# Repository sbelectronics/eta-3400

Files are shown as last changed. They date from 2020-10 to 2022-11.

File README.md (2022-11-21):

# Scott's ETA-3400 Memory/IO Accessory Remake
(c) Scott Baker, http://www.smbaker.com/

youtube video: https://www.youtube.com/watch?v=gP17z7haC4o&ab_channel=smbakeryt

## Purpose

The ETA-3400 was a memory/IO accessory for Heathkit's ET-3400 and ET-3400-A trainers. It added a serial port, a cassette port, up to 4K of RAM, and 4K of ROM. The ROM included a terminal monitor that you could use to operate the trainer over serial, as well as a "Tiny Basic" ROM that allowed you to program the trainer in the BASIC programming language.

This project is a remake of that board, using slightly more modern components, but still in the vintage theme of the original.

## Recompiling the ATF16V8

The ATF16V8 is a programmable logic device that implements the IO addressing and some control line manipulation. It's programmed in a languaged called CUPL. You'll need the [WinCUPL tool](https://www.microchip.com/design-centers/fpgas-and-plds/splds-cplds/pld-design-resources) from Microchip in order to recompile the PLD. The desired output is the JED file, which you can program using a programmer such as TL866 with minipro software.

## Burning the ROM

I wrote a small python tool, makerom.py, that loaded the original heathkit ROMs into a 4K rom image (the way they're addressed is a little bit weird, the trainer puts them at 0x1400 to 0x23FF). I used a TL866 with minipro to burn it to a 28C64 EEPROM chip.

You might notice that roms/combined.bin is 5K instead of 4K. That's a mistake (the last 1K is all zeros), but that's also the way it was when I burned my ROM and made my video, so I left it as-is. In the future, I may look into finding a way to load more programs into the remainder of the ROM and make it addressable.

## Setting up the raspberry pi zero

The raspberry pi zero is entirely optional (the board features a RS232 port that can be used with an external terminal), but offers the ability to build a terminal directly into your ETA-3400. Some instructions on setting up the Pi Zero W

```bash
# disable serial console
sudo raspi-config
  5 - interfacing options
    P6 - serial
        No login shell
        Yes serial interface enabled

# install minicom
sudo apt-get -y install minicom
sudo minicom -s
  Port - /dev/serial0
  Baud - 2400
  Bits - 7,E,1
  Flow Control - off

# as an alternative to minicom, picocom can be used
sudo apt-get -y install picocom
picocom /dev/ttyS0 --baud 2400 -p 1 -d 7 -y e

Note: You'll want to set an end-of-line delay in minicom or picocom if you want to be able to do text uploads to basic. I recommend 325 milliseconds. Otherwise, your terminal
might send the next character while basic is saving the freshly-entered line, and the first character of the next line will be lost.
```

## Static RAM Notes

My tests of several 62256 RAM variants that I obtained. Note that I have only performed a short test on each one to verify whether
BASIC loaded properly and was able to run a short program. Your mileage may vary.

* AS6C62256-55PCN (Mouser) 55ns part DOES NOT WORK correctly. 70ns part (-70PCN) is fine but hard to find.
* HM62256LP-12 (Jameco 42850). According to catalog is a 150ns part, but as received with -12 number is probably 120ns. Tested and works.
* KM62256BLP-10 (Jameco 42833). 100ns. Tested and works.
* HM62256BLP-7 (Jameco 82472). 70ns low power. DOES NOT WORK.
* MS62256L-70PC (ebay). 70ns. Tested and works.
* CY62256NLL-70PXC. 70ns. Tested and works.

## Gerbers

The gerbers are present in the gerbers directory.

* gerbers/v-0.2-initial .. This was my initial order, sent to jlcpcb, to make the boards used in the video.

## Resources and Acknowlegements

* The [ET-3400 group](https://groups.io/g/ET-3400) is a great resource, and several people there were helpful and supportive of this project.

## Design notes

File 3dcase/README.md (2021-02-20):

# 3D Printed Case

Makes extensive use of heat-set threadserts to connect the pieces together. Double-faced tape is used to stick
some mounts onto the bottom of the trainer, and then magnets are used to attach the case to the mounts. This
makes the case easily removable (my youtube video ought to give a reasonable idea on how the case snaps on
and off).

Here is a list of hardware necessary to complete the case:

* Magnets - use 10mm x 3mm, commonly available on Amazon
* M2.5 machine screws - Usually a small assortment from Amazon will yield a variety of acceptable sizes
* 2.5mm heat-set thread inserts - I usually get these on eBay under the auction description "Qty 100 M2.5 2.5mm M2.5-0.45 Brass Threaded Heat Set Screw Inserts - 3D Printing"

Print the following:

* (1) eta-3400-front.stl - front panel
* (2) eta-3400-side.stl - sides
* (1) eta-3400-back.stl - back panel
* (1) eta-3400-tray.stl - attaches to the back panel and holds the PCB
* (1) eta-3400-base.stl - attachs between the tray and the front panel, providing additional rigidity
* (2) eta-3400-mount.stl - sticks to the trainer with double-faced tape

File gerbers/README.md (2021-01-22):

This directory holds gerbers that can be used to fabricate the pcboards.

A few different ET-3400 related projects are in here

v0.10 and v0.9 hold the gerbers for the ETA-3400 memory/io board. v0.10 is the latest.

et-3400-6809-v0.2 holds gerbers for my clone for the 6809 adapter. This adapter is a separate project
and is not needed to build the memory/io accessory.

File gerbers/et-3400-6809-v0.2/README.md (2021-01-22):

This directory holds my clone of the ET-3404 6089 adapter.

More about it at https://www.smbaker.com/cloning-the-et-3404-6809-adapter-for-the-heathkit-et-3400

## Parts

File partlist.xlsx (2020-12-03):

Part | Value | Quantity | Description | Source
C1 | 0.0047uF | 1 |  | digikey BC2683CT-ND
C2 | 2.2uF | 1 |  | digikey 445-173575-1-ND
C3 | 0.047uF | 1 |  | digikey BC2686CT-ND
C4-C14 | 0.1uF | 11 | bypass capacitor | digikey 399-4264-ND
 | 470uf/16V | 1 | additional stability when using pi; place across the 5V and GND pins of SV1
D1, D2 | 1N4148 | 2 |  | digikey 1N4148FS-ND
IC1 | 28C64 | 1 | EEPROM | digikey AT28C64B-15PU-ND
IC2 | AS6C62256 | 1 | RAM | digikey 1450-1182-5-ND (use the 70ns version, not the 55ns)
IC3 | 6821 PIA | 1 | PIA | ebay
IC4 | ATF16V8BP3 | 1 | PLD address decode | digikey ATF16V8B-15PU-ND
IC5 | MAX202 | 1 | serial driver | digikey MAX202ECPE+-ND
IC6 | MC3302P | 1 | comparator | digikey 296-17223-5-ND
J1 | DCJACK 5.5x2.1 | 1 | [Optional] external power | digikey CP-002A-ND (not verified, looks right)
JP1 | 1x3 header |  | [Optional] spare input to PLD | digikey, S1012EC-40-ND (cut to size)
JP2 | 2x6 header |  | Baud select jumper
JP3 | 1x2 header |  | Jumper, enables power from ET3400
JP4 | 1x2 header |  | Jumper, enables power to pi socket
JP5 | 1x3 header |  | Jumper, cassette output gain
JP6 | 2x2 header |  | Jumpers, ser output | digikey, S2012EC-20-ND (cut to size)
JP7 | 2x2 header |  | Jumpers, max202
R1, R5, R8 | 100K | 3 |  | digikey S100KCACT-ND
R2, R4, R9, R10 | 1K | 4 |  | digikey S1KCACT-ND
R3, R7, R11, R20 | 10K | 4 |  | digikey S10KCACT-ND
R6 | 3.3K | 1 |  | digikey S3.3KCACT-ND
R12 | 100 ohm | 1 |  | digikey S130CACT-ND
R13-R19 | 150 ohm | 7 | RasPi protection resistors | digikey S150CACT-ND
R21 | 0 (jumper) | 1 | a chunk of wire will do
RN1 | 2.2K x 6 SIP | 1 | 2.2Kx6 bussed sip resistor | digikey 4607X-101-222LF-ND
SV1 | 1x5 RA header | 1 | [Optional] I2C header from pi | digikey S1111EC-40-ND (cut to size)
SV2 or SV3 | 1x4 RA header | 1 |  | digikey S1132EC-40-ND (cut to size, tall)
U$2 | 2x40 header | 1 |  | digikey, S2012EC-20-ND (cut to size)
X1 | RASPI_BOAR |  | [Optional] Header for Pi Zero W
X2 | DB25 | 1 | DB25 connector | Digikey, AE10935-ND
 | shunt jumpers |  |  | Digikey, S9337-ND
CAB1 | 40-ribbon |  | 40 pin ribbon cable |  | ETA-3400 to ET-3400 cable
IDC1, IDC2 | 2x20 IDC conn |  | 2x20 IDC ribbon cable connector |  | ETA-3400 to ET-3400 connectors

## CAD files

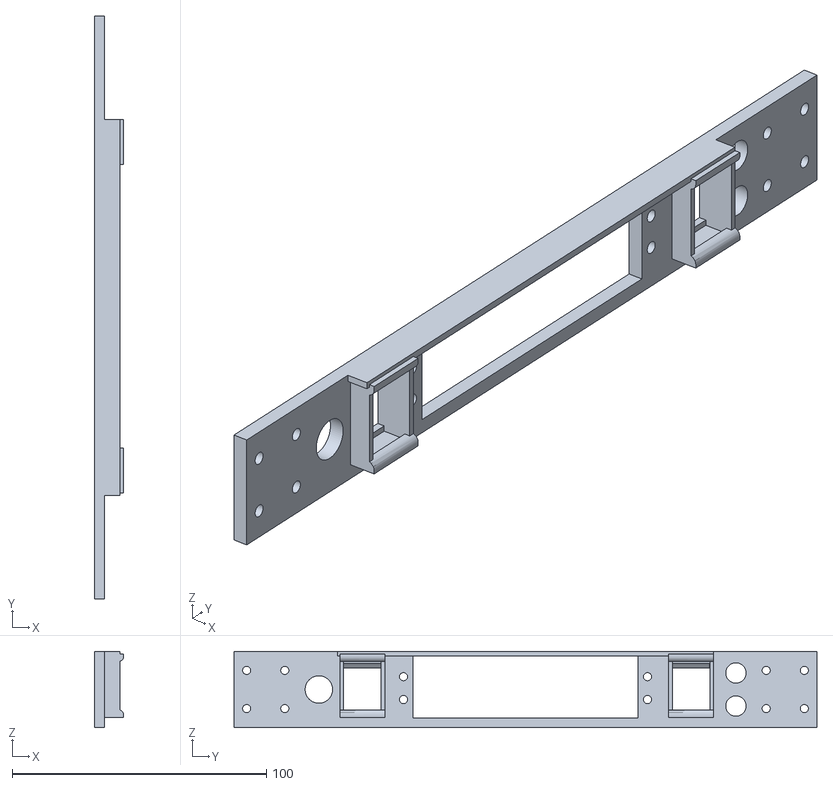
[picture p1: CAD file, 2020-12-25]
3dcase/eta-3400-back.stl
11.5 x 229.4 x 30.0

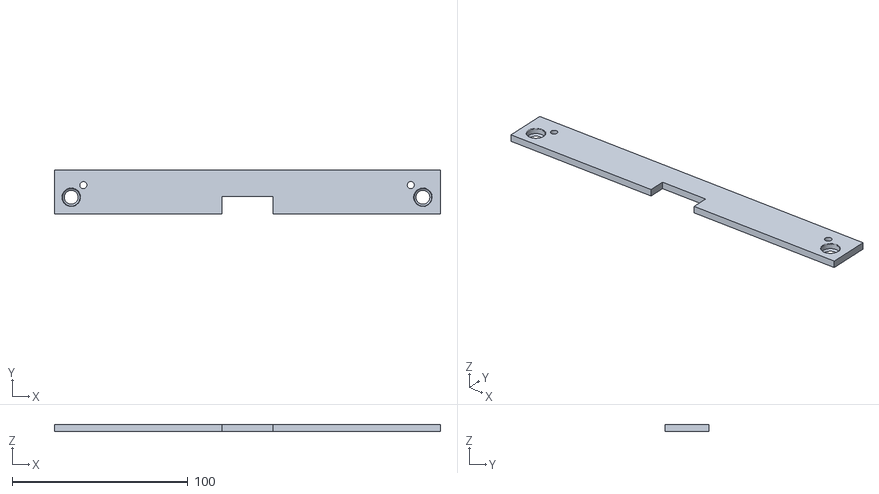
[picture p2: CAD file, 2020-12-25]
3dcase/eta-3400-mount.stl
219.5 x 25.0 x 4.00

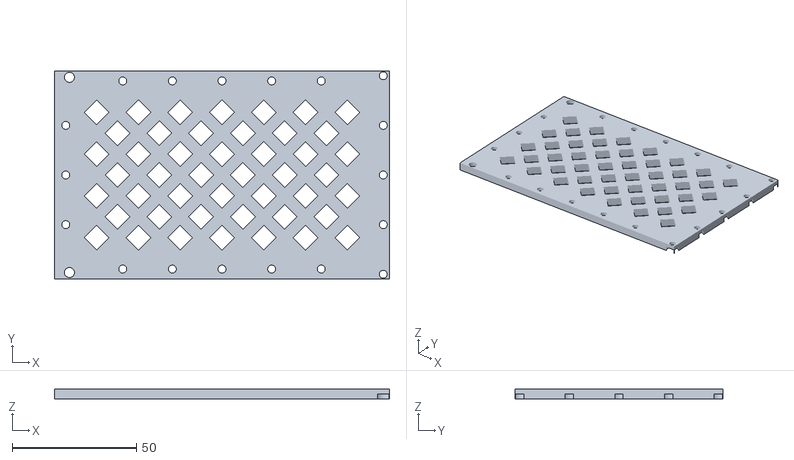
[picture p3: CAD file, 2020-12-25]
3dcase/eta-3400-base-perforated.stl
135.0 x 83.8 x 4.00

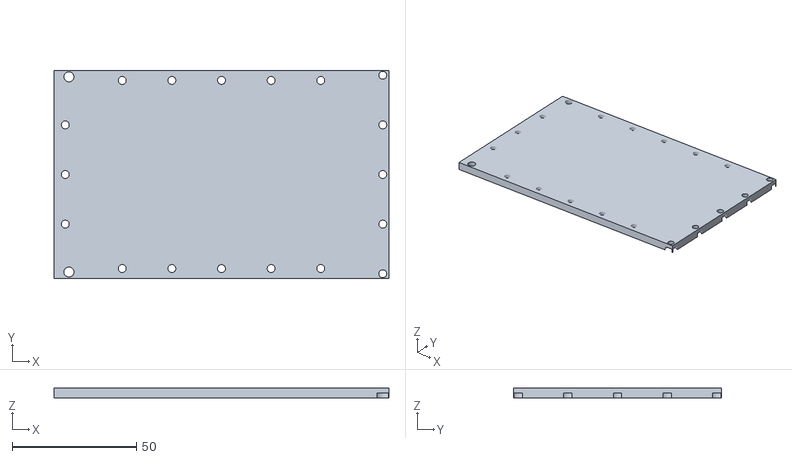
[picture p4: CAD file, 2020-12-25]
3dcase/eta-3400-base.stl
135.0 x 83.8 x 4.00

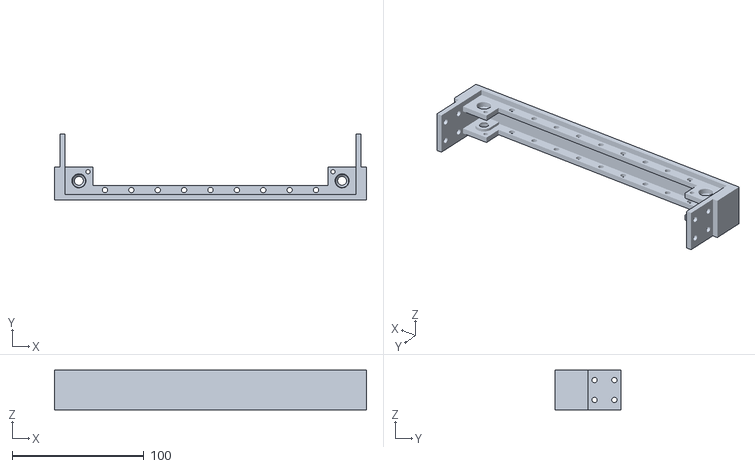
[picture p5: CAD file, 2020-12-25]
3dcase/eta-3400-side.stl
236.5 x 50.0 x 30.0

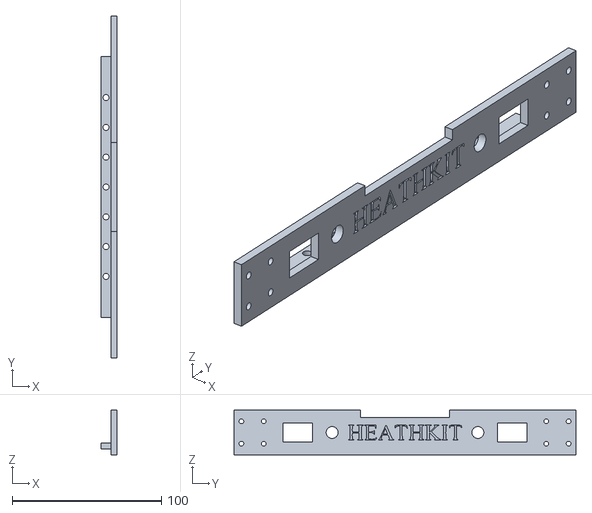
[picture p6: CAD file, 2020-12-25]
3dcase/eta-3400-front.stl
11.0 x 229.4 x 30.0

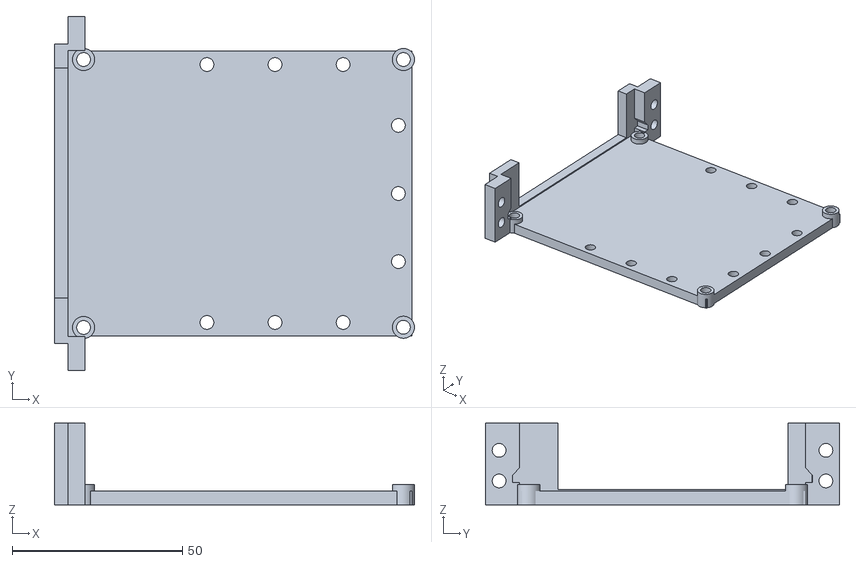
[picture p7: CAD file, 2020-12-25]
3dcase/eta-3400-tray.stl
105.8 x 104.0 x 24.0

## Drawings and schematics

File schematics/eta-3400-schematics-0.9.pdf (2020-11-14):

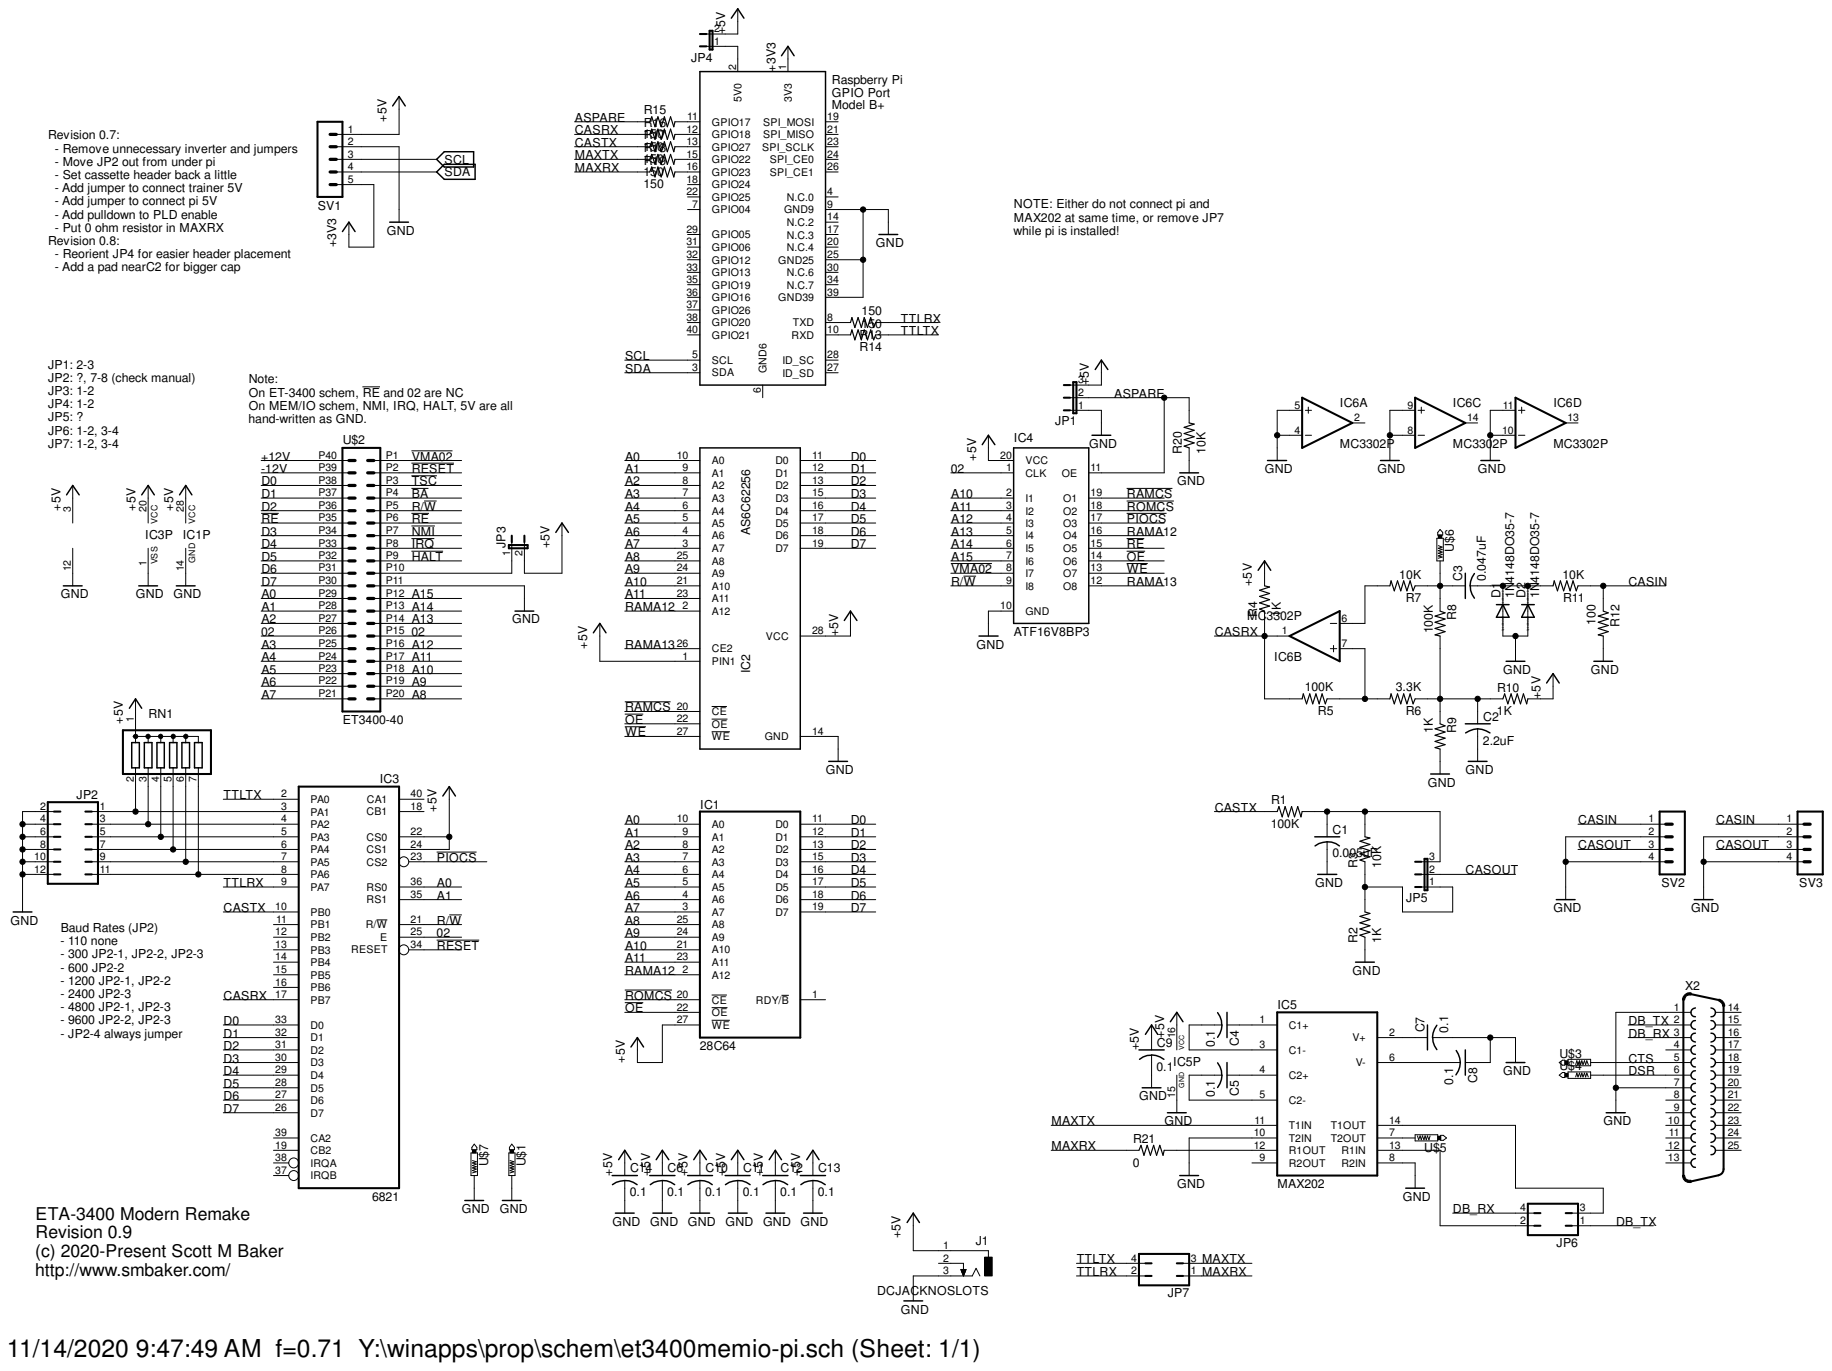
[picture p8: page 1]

Revision 0.7:
- Remove unnecessary inverter and jumpers
- Move JP2 out from under pi
- Set cassette header back a little
- Add jumper to connect trainer 5V
- Add jumper to connect pi 5V
- Add pulldown to PLD enable
- Put 0 ohm resistor in MAXRX
Revision 0.8:
- Reorient JP4 for easier header placement
- Add a pad nearC2 for bigger cap

NOTE: Either do not connect pi and
MAX202 at same time, or remove JP7
while pi is installed!

Note:
On ET-3400 schem, RE and 02 are NC
On MEM/IO schem, NMI, IRQ, HALT, 5V are all
hand-written as GND.

ETA-3400 Modern Remake
Revision 0.9
(c) 2020-Present Scott M Baker
http://www.smbaker.com/

GND GND GND GND GND

11/14/2020 9:47:49 AM f=0.71 Y:\winapps\prop\schem\et3400memio-pi.sch (Sheet: 1/1)

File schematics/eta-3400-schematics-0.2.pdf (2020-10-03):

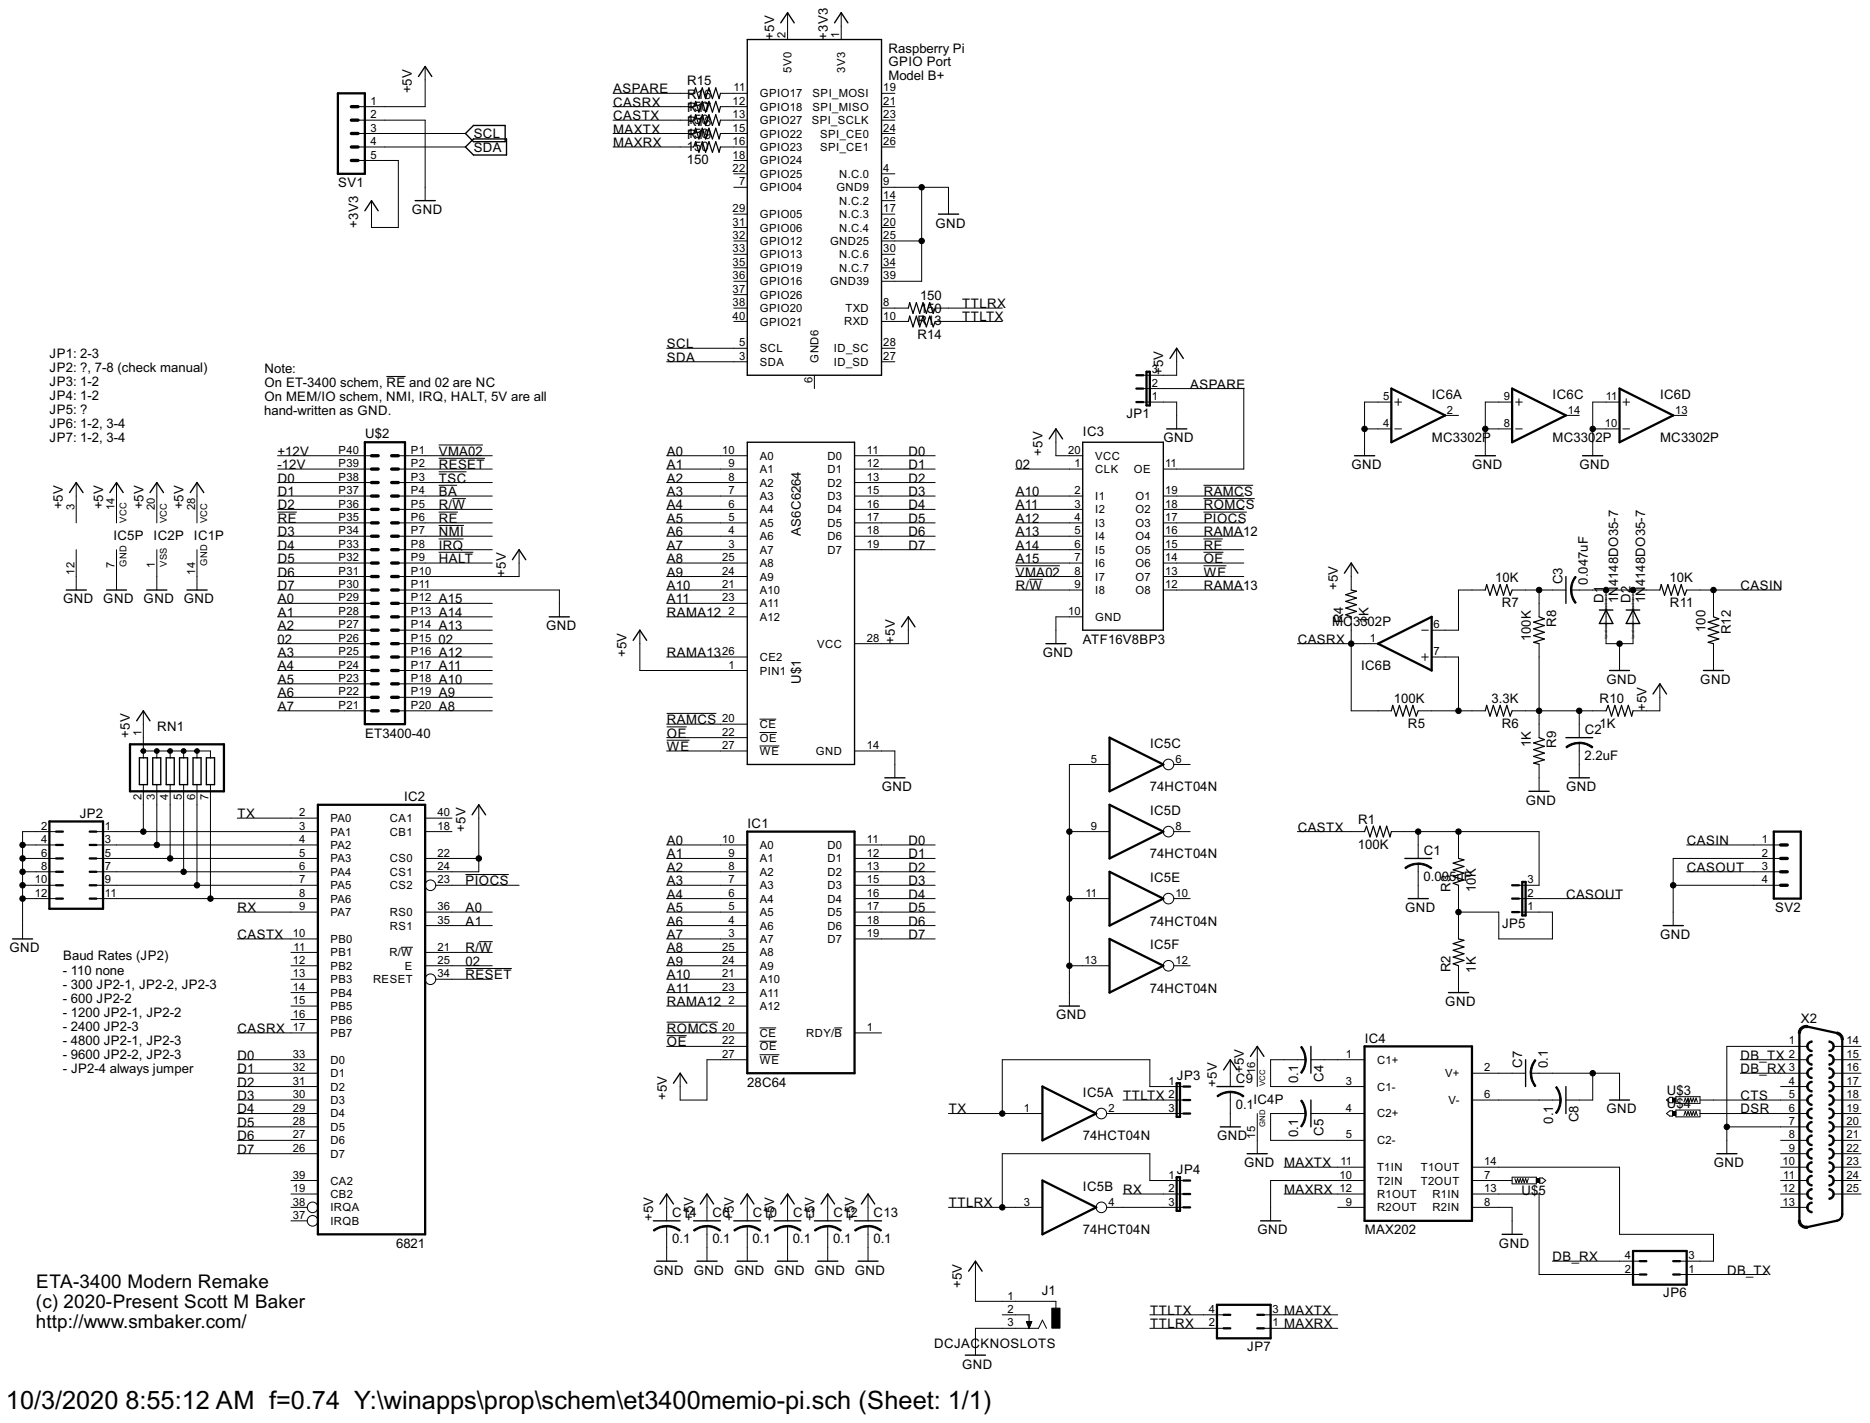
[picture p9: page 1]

Raspberry Pi GPIO Port Model B+

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

ETA-3400 Modern Remake
(c) 2020-Present Scott M Baker http://www.smbaker.com/

GND GND GND GND GND

10/3/2020 8:55:12 AM f=0.74 Y:\winapps\prop\schem\et3400memio-pi.sch (Sheet: 1/1)

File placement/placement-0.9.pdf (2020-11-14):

# (pi upside-down)

3 | 2 | 1

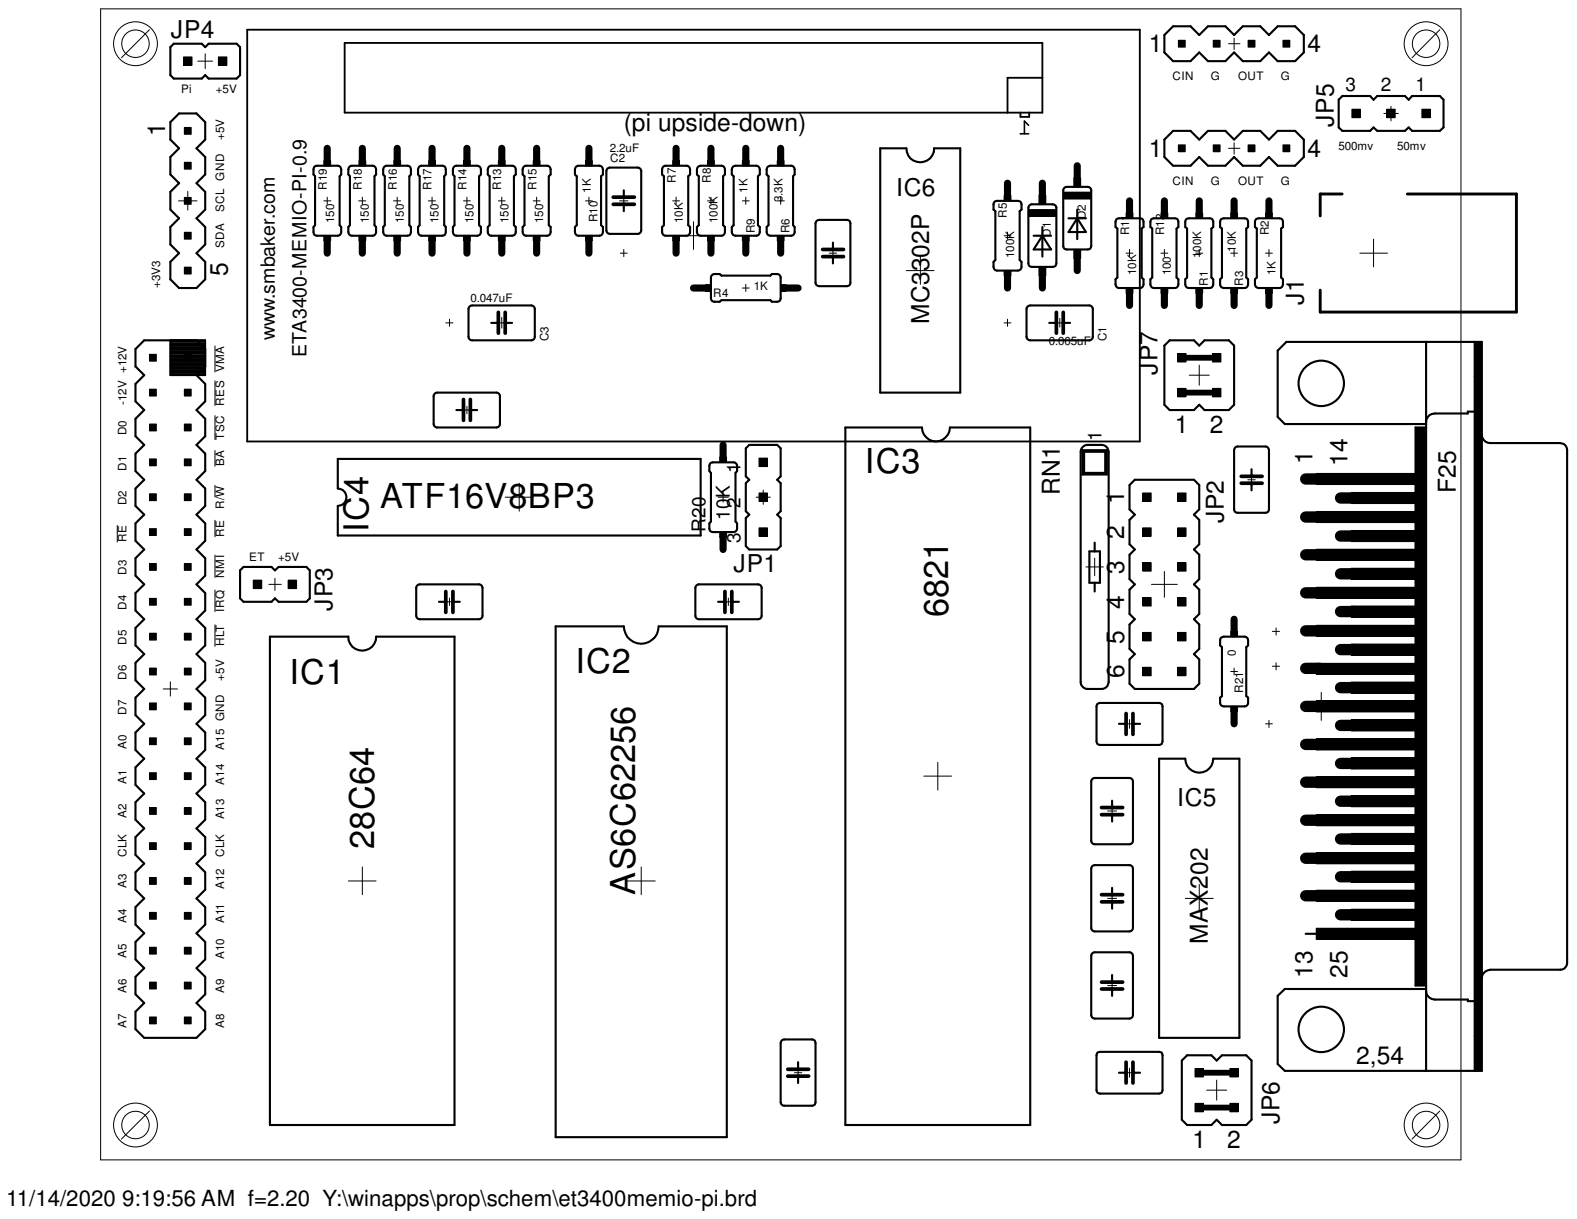
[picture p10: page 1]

VMA RES TSC BA R/W RE NMI IRQ HLT +5V GND A15 A14 A13 A12 A11 A10 CLK A9

11/14/2020 9:19:56 AM f=2.20 Y:\winapps\prop\schem\et3400memio-pi.brd

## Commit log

2020-10-03 check in gerbers
    [et3400memio-pi.GBL, et3400memio-pi.GBO, et3400memio-pi.GBS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]
2020-10-03 check in schematic
2020-10-05 working on LOD sample game
2020-11-14 check in 0.9 schematic and placement
    [partlist.xlsx]
2020-11-15 check in part list update
    [partlist.xlsx]
2020-12-03 check in v0.9 and v0.10 gerbers
    [et3400memio-pi.GBL, et3400memio-pi.GBO, et3400memio-pi.GBS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]
2020-12-03 add DB25 to BOM
    [partlist.xlsx]
2020-12-25 check in stl files for the 3dprinted case
    [eta-3400-back.stl, eta-3400-base-perforated.stl, eta-3400-base.stl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]
2021-01-22 add gerbers for the 6809 adapter too
    [et3400-6809.GBL, et3400-6809.GBO, et3400-6809.GBS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]
2021-02-20 more notes on case assembly
